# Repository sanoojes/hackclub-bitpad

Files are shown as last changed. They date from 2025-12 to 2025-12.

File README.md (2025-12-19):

# BitPad

A simple, customizable macropad with hot swapable keys, fully programmable keys, per-key RGB
lighting, multiple profiles for gaming, programming, editing, and more. uses QMK Firmware

## CAD

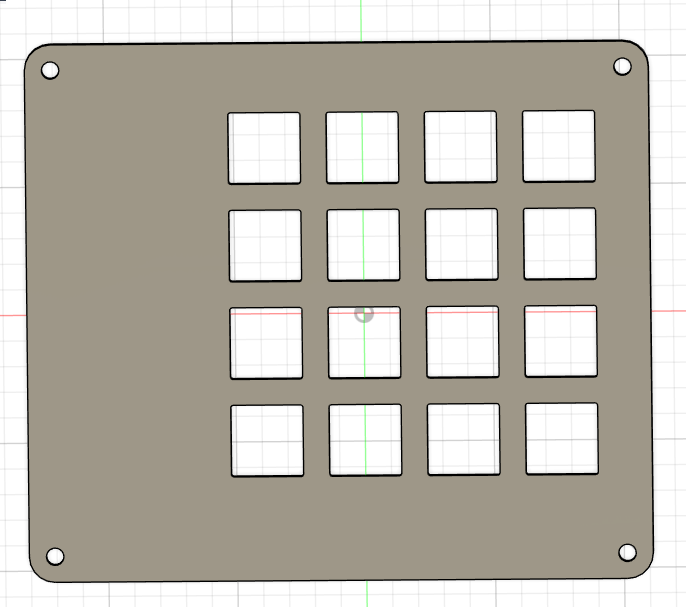
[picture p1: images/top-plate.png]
top_plate

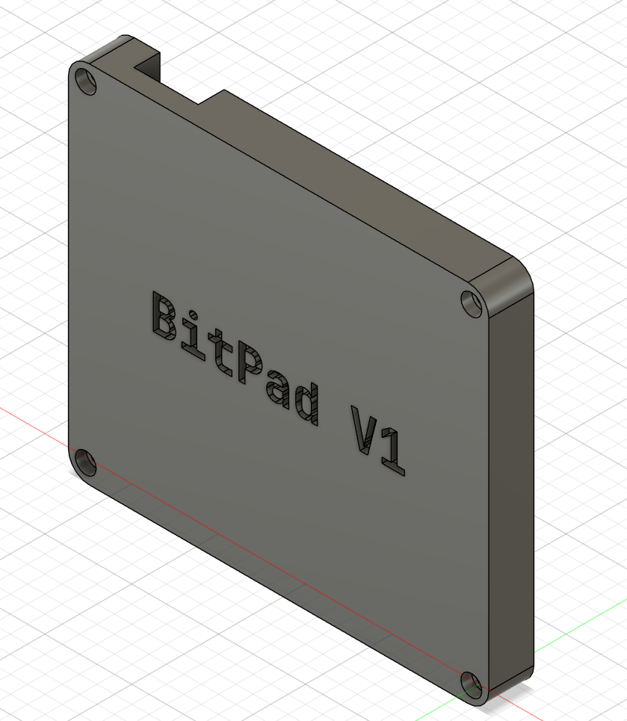
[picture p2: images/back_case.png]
back_case

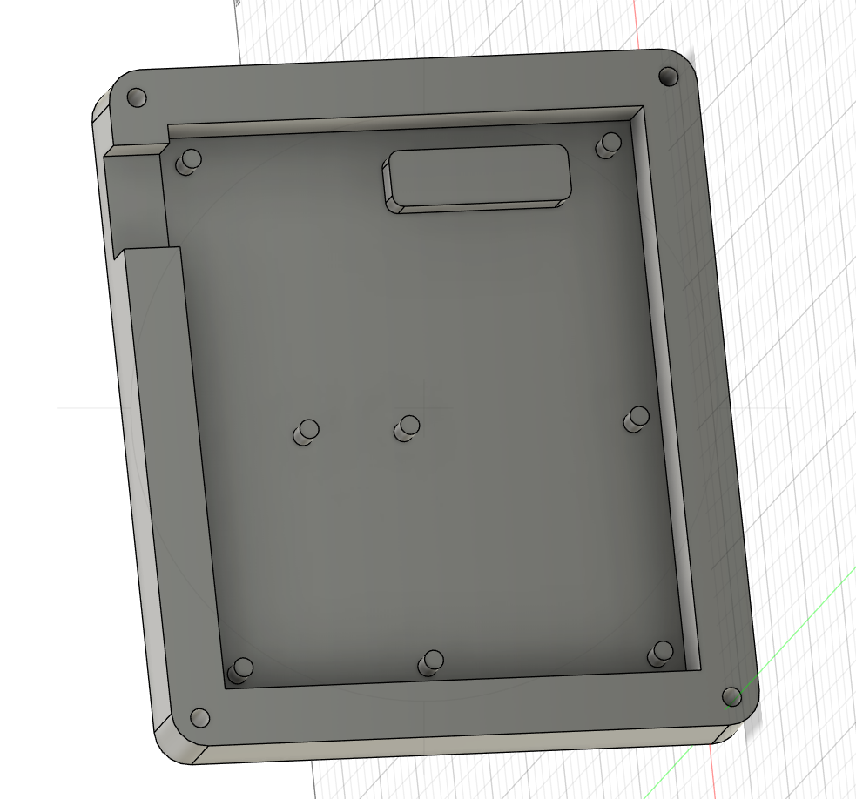
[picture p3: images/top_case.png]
top_case


## PCB

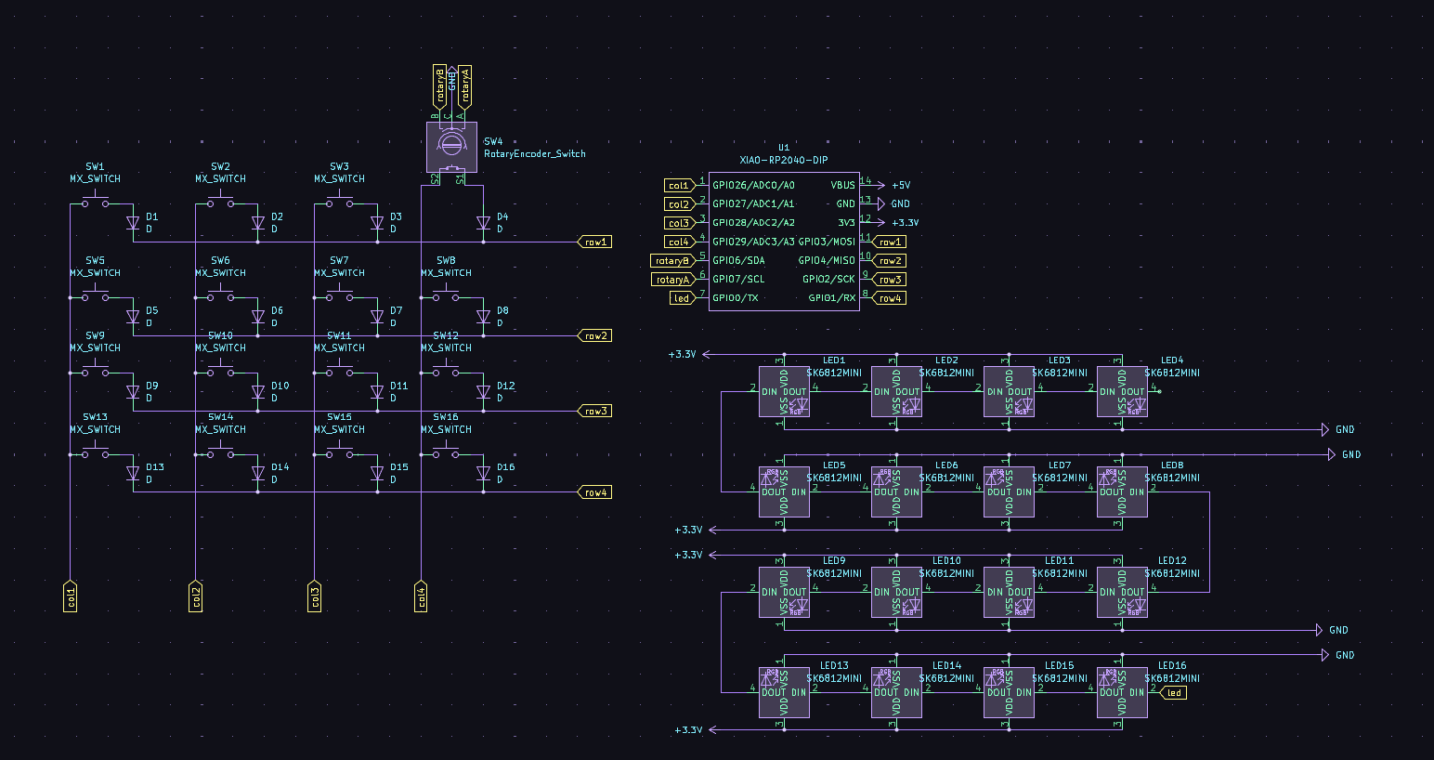
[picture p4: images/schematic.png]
schematics
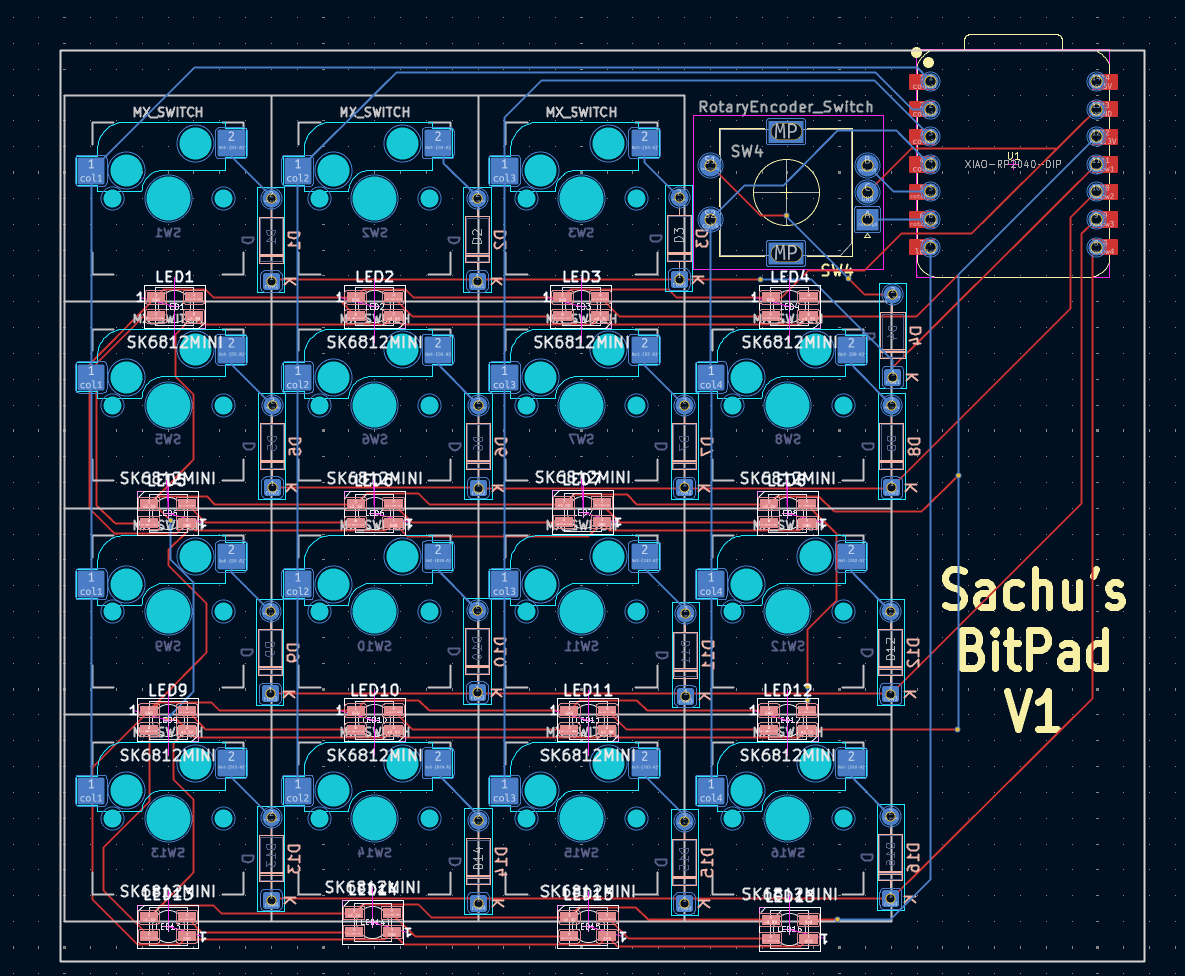
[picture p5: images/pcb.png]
pcb
 

## Firmware

Firmware available at [firmware/](firmware/) firmware will be tweaked and updated after i get the materials.

## BOM (Bill of materials)

Here's what I used for the device:

- 1x XIAO_RP2040 module
- 1x SK6812 Mini LEDs
- 1x EC11 Rotary Encoder
- 4x M3x16mm screws
- 4x M3x5mmx4mm inserts
- 16x Cherry MX Hotswappable Switches
- 16x DSA Keycaps
- 3D Printed Case

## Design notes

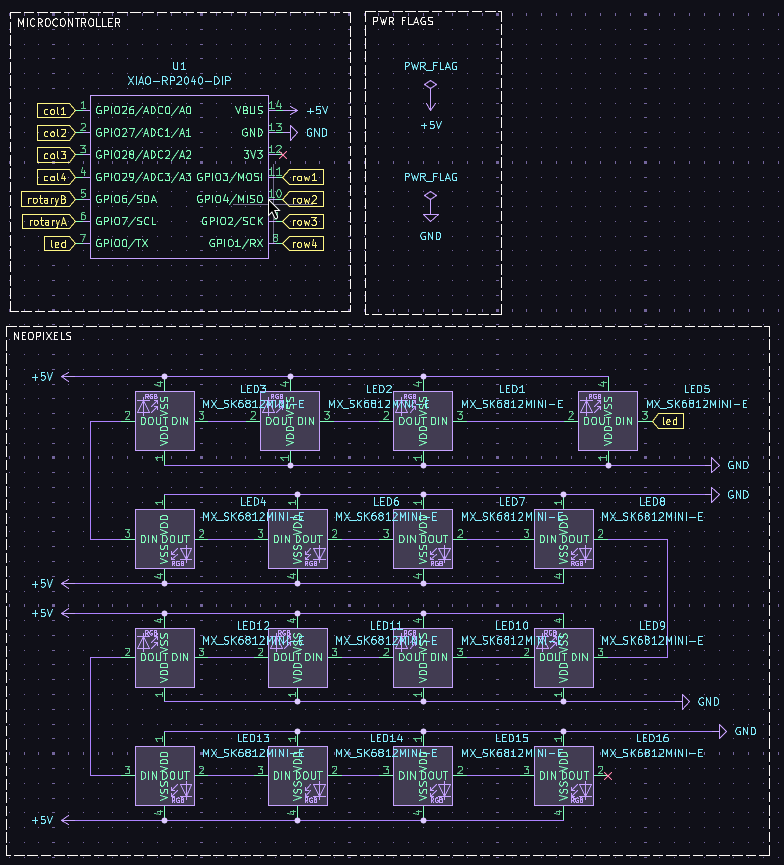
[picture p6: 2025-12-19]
images/schematic2.png

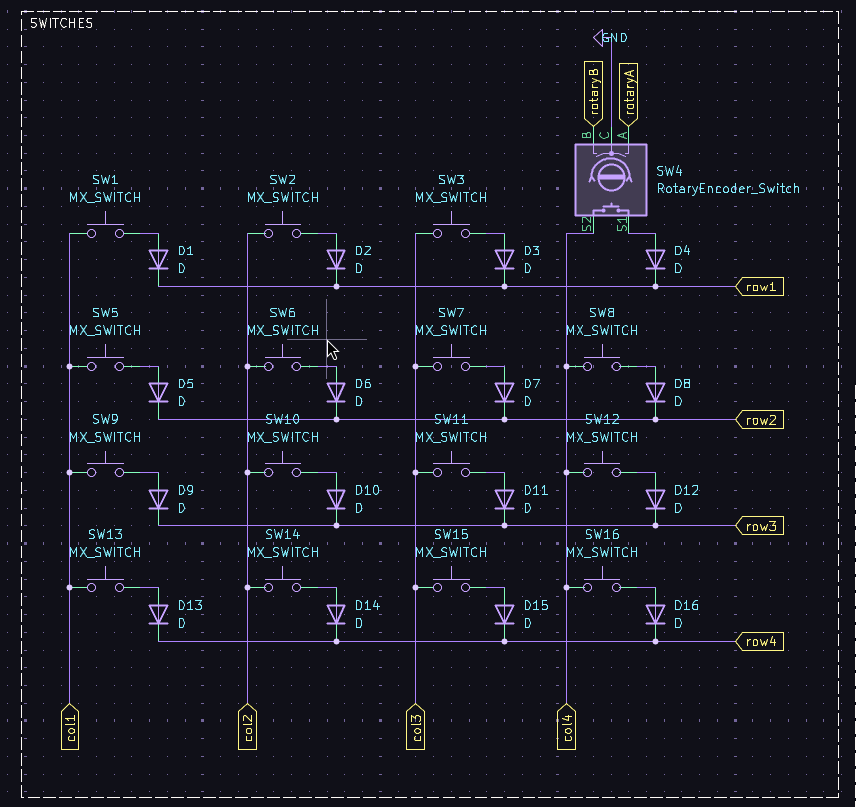
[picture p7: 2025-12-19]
images/schematic1.png

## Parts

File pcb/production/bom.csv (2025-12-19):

Designator | Footprint | Quantity | Value | LCSC Part #
D1, D10, D11, D12, D13, D14, D15, D16, D2, D3, D4, D5, D6, D7, D8, D9 | D_DO-35_SOD27_P7.62mm_Horizontal | 16 | D
LED1, LED10, LED11, LED12, LED13, LED14, LED15, LED16, LED2, LED3, LED4, LED5, LED6, LED7, LED8, LED9 | LED_MX_6028R | 16 | MX_SK6812MINI-E
SW1, SW10, SW11, SW12, SW13, SW14, SW15, SW16, SW2, SW3, SW5, SW6, SW7, SW8, SW9 | SW_MX_HS_CPG151101S11_1u | 15 | MX_SWITCH
SW4 | RotaryEncoder_Alps_EC11E-Switch_Vertical_H20mm | 1 | RotaryEncoder_Switch
U1 | XIAO-RP2040-DIP | 1 | XIAO-RP2040-DIP

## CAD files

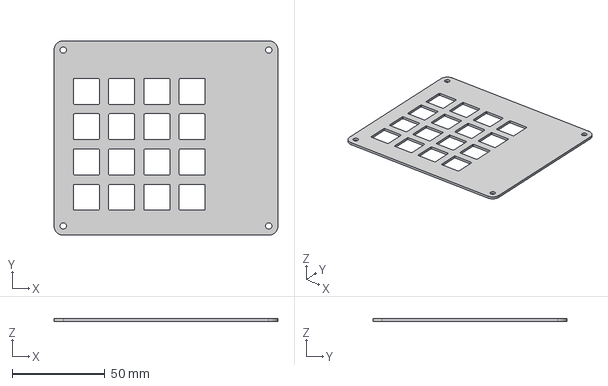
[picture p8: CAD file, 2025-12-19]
cad/top-plate.step
121.0 x 105.0 x 1.50 mm

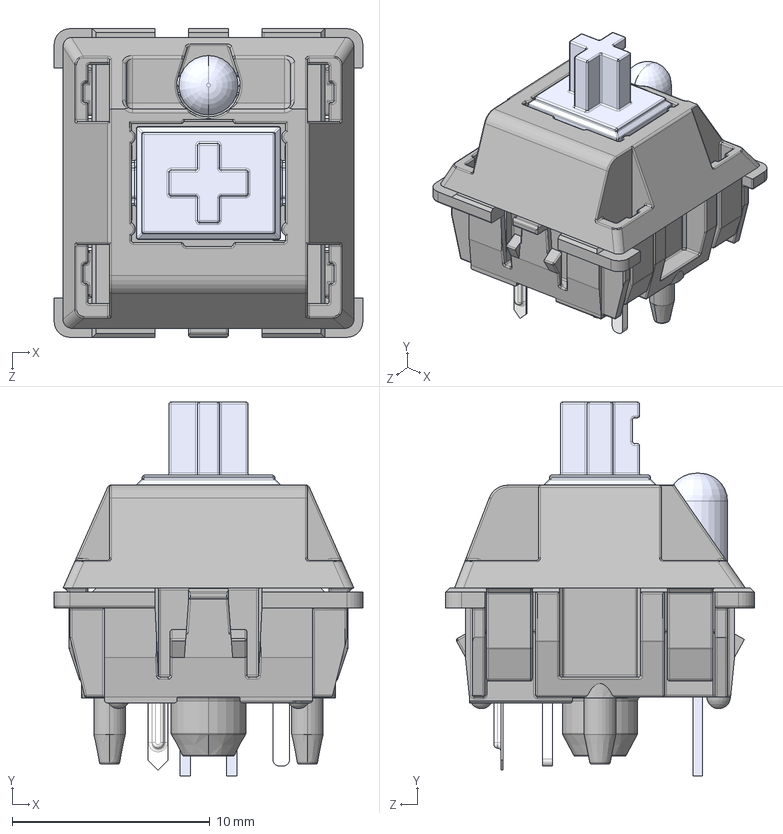
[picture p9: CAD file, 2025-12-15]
pcb/3dmodels/MX .STEP
15.6 x 18.9 x 15.6 mm
MX 轴 按键′_ü___¨1
MX 轴 轴体áì_¨￠¨__
MX粣 拸簽LEDLEDLED
MX轴 轴体 底部 μ×2__默认_á2____è_
针脚___默认__è_

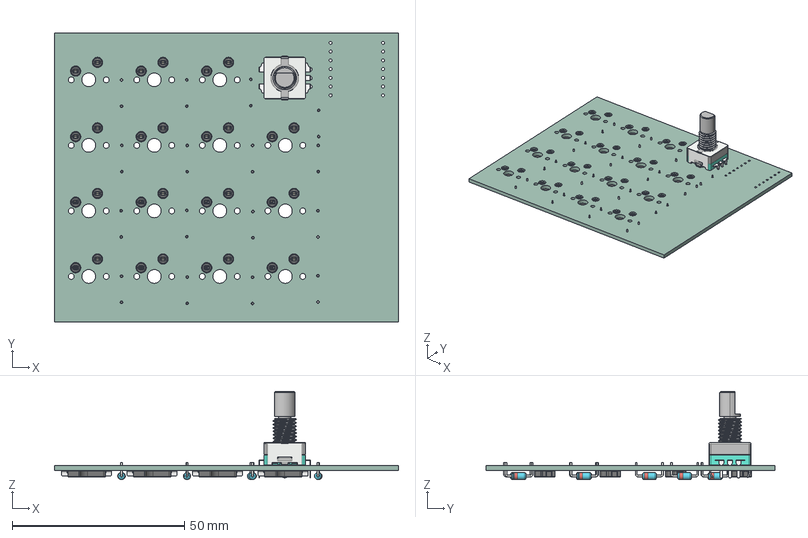
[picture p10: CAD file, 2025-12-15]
pcb/pcb.step
100.0 x 84.0 x 25.6 mm
rotary-encoder
D_DO-35_SOD27_P7.62mm_Horizontal x 16
MX-Hotswap-Socket x 15
pcb_PCB

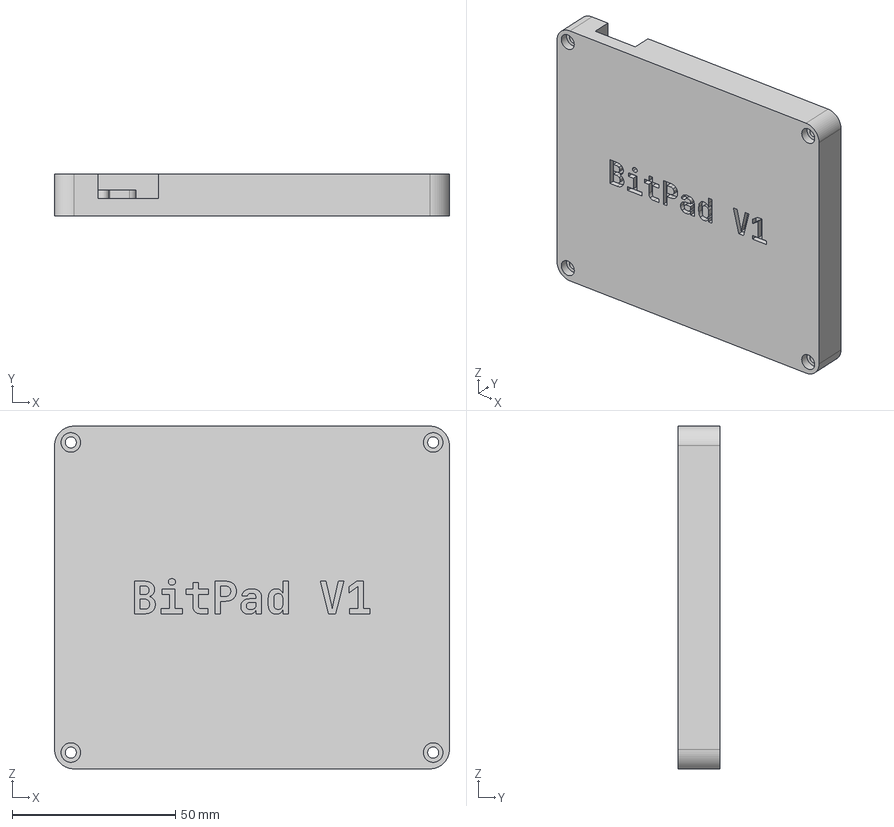
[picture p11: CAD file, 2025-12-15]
cad/case.step
121.0 x 13.0 x 105.0 mm

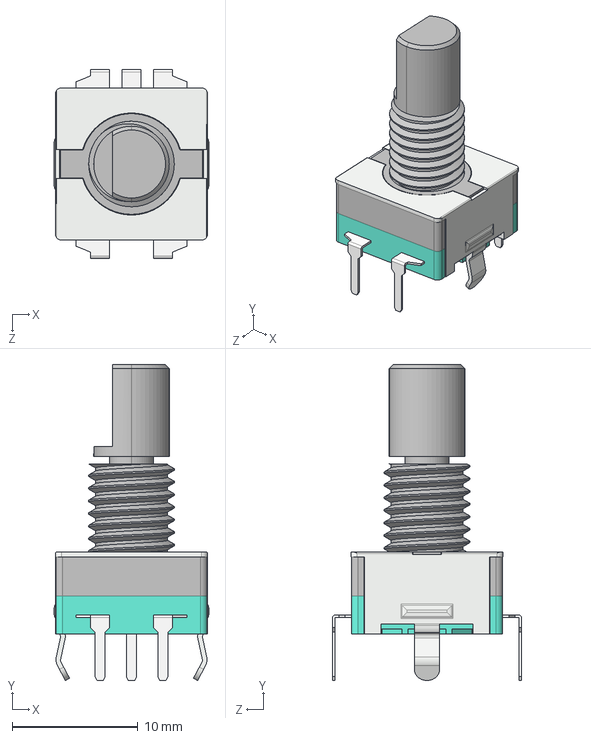
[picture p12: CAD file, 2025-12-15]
pcb/3dmodels/rotary-encoder.STEP
12.3 x 25.1 x 15.0 mm

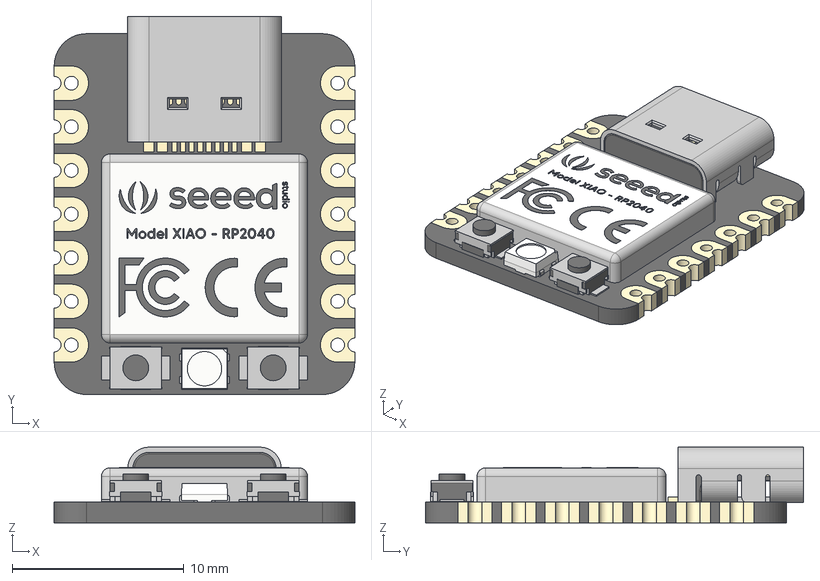
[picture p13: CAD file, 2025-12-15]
pcb/3dmodels/Seeed Studio XIAO RP2040 v26.step
17.5 x 22.0 x 4.40 mm
type-c v2
smd_button v3
DOUT
DIN
VSS
VDD
smd_button v3(Mirror)

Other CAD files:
cad/case.f3d
cad/case.stl
cad/top-plate.f3d

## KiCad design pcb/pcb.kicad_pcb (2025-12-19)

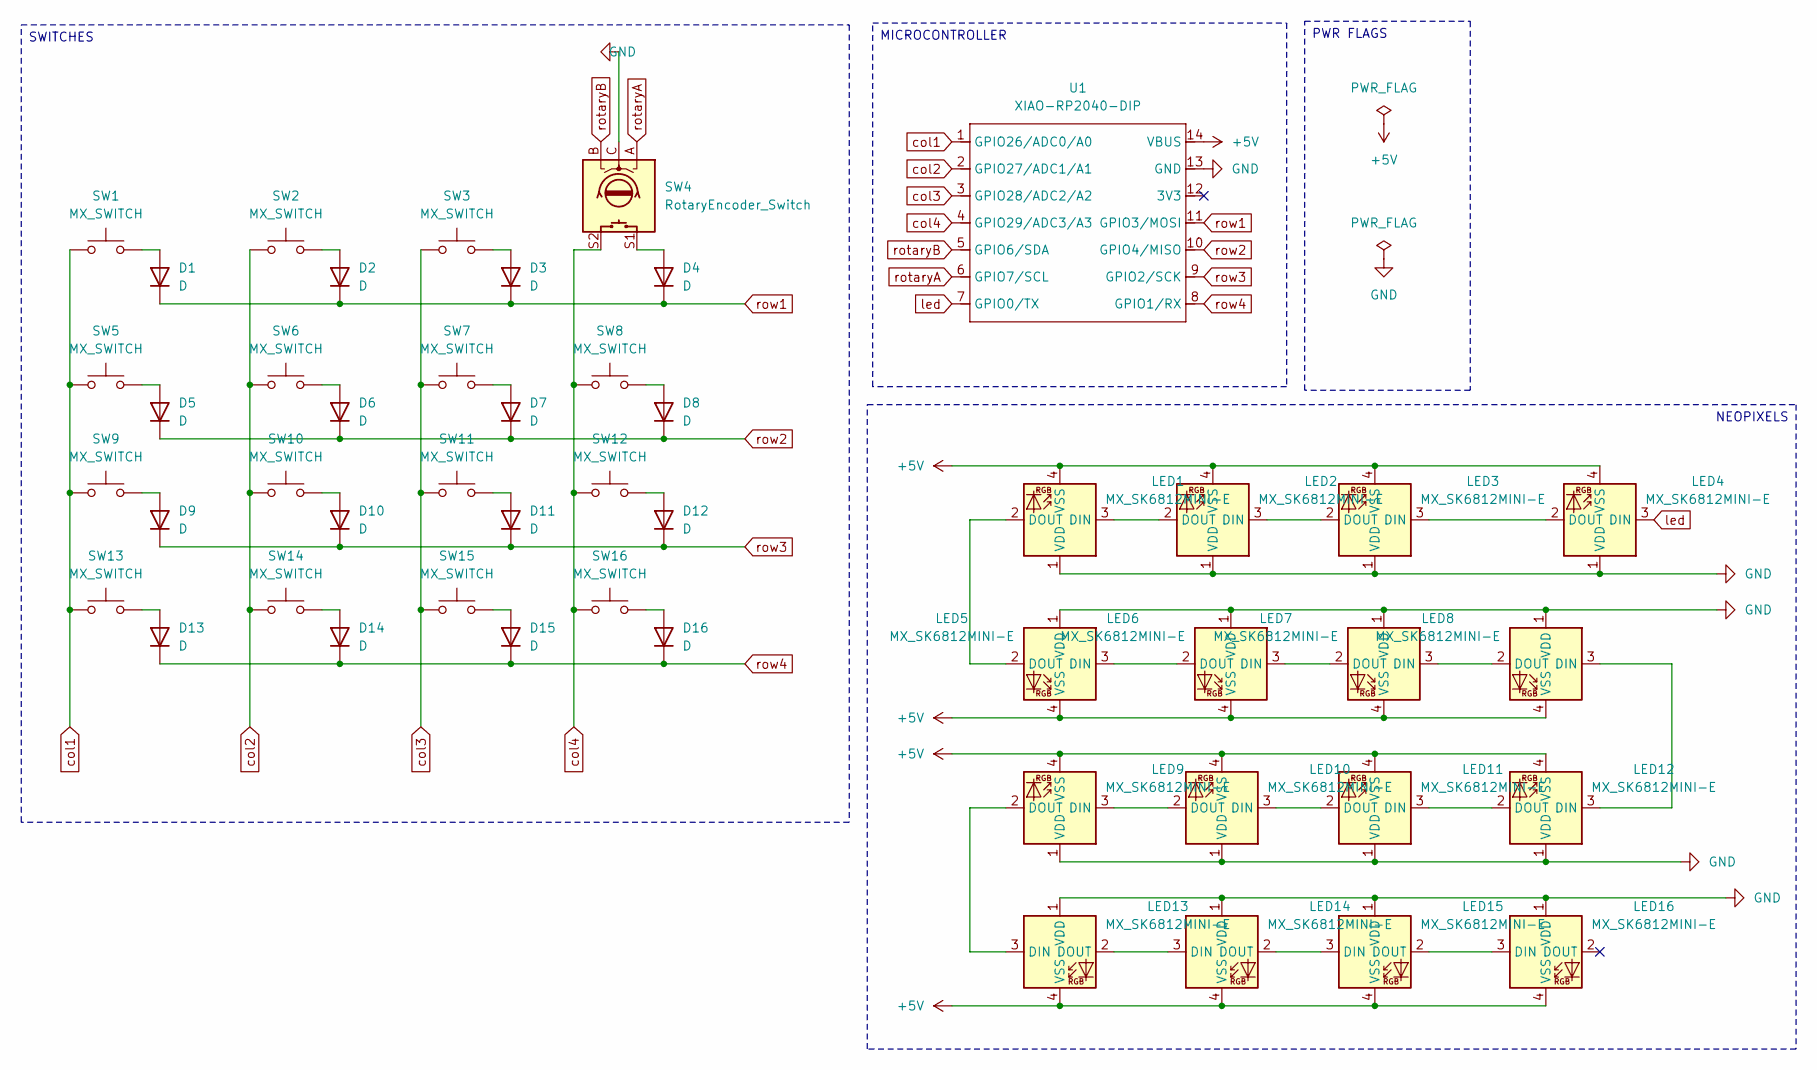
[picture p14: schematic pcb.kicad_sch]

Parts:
D1, D2, D3, D4, D5, D6, D7, D8, D9, D10, D11, D12, D13, D14, D15, D16: D; D_DO-35_SOD27_P7.62mm_Horizontal
LED1, LED2, LED3, LED4, LED5, LED6, LED7, LED8, LED9, LED10, LED11, LED12, LED13, LED14, LED15, LED16: MX_SK6812MINI-E; LED_MX_6028R
SW1, SW2, SW3, SW5, SW6, SW7, SW8, SW9, SW10, SW11, SW12, SW13, SW14, SW15, SW16: MX_SWITCH; SW_MX_HS_CPG151101S11_1u
SW4: RotaryEncoder_Switch; RotaryEncoder_Alps_EC11E-Switch_Vertical_H20mm
U1: XIAO-RP2040-DIP

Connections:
+5V: LED1.4 (VSS), LED2.4 (VSS), LED3.4 (VSS), LED4.4 (VSS), LED5.4 (VSS), LED6.4 (VSS), LED7.4 (VSS), LED8.4 (VSS), LED9.4 (VSS), LED10.4 (VSS), LED11.4 (VSS), LED12.4 (VSS), LED13.4 (VSS), LED14.4 (VSS), LED15.4 (VSS), LED16.4 (VSS), U1.14 (VBUS)
GND: LED1.1 (VDD), LED2.1 (VDD), LED3.1 (VDD), LED4.1 (VDD), LED5.1 (VDD), LED6.1 (VDD), LED7.1 (VDD), LED8.1 (VDD), LED9.1 (VDD), LED10.1 (VDD), LED11.1 (VDD), LED12.1 (VDD), LED13.1 (VDD), LED14.1 (VDD), LED15.1 (VDD), LED16.1 (VDD), SW4.C, U1.13 (GND)
unnamed: D1.2 (A), SW1.2
unnamed: D2.2 (A), SW2.2
unnamed: D3.2 (A), SW3.2
unnamed: D4.2 (A), SW4.S1
unnamed: D5.2 (A), SW5.2
unnamed: D6.2 (A), SW6.2
unnamed: D7.2 (A), SW7.2
unnamed: D8.2 (A), SW8.2
unnamed: D9.2 (A), SW9.2
unnamed: D10.2 (A), SW10.2
unnamed: D11.2 (A), SW11.2
unnamed: D12.2 (A), SW12.2
unnamed: D13.2 (A), SW13.2
unnamed: D14.2 (A), SW14.2
unnamed: D15.2 (A), SW15.2
unnamed: D16.2 (A), SW16.2
unnamed: LED1.3 (DIN), LED2.2 (DOUT)
unnamed: LED1.2 (DOUT), LED5.2 (DOUT)
unnamed: LED2.3 (DIN), LED3.2 (DOUT)
unnamed: LED3.3 (DIN), LED4.2 (DOUT)
unnamed: LED5.3 (DIN), LED6.2 (DOUT)
unnamed: LED6.3 (DIN), LED7.2 (DOUT)
unnamed: LED7.3 (DIN), LED8.2 (DOUT)
unnamed: LED10.3 (DIN), LED11.2 (DOUT)
unnamed: LED9.3 (DIN), LED10.2 (DOUT)
unnamed: LED11.3 (DIN), LED12.2 (DOUT)
unnamed: LED8.3 (DIN), LED12.3 (DIN)
unnamed: LED9.2 (DOUT), LED13.3 (DIN)
unnamed: LED13.2 (DOUT), LED14.3 (DIN)
unnamed: LED14.2 (DOUT), LED15.3 (DIN)
unnamed: LED15.2 (DOUT), LED16.3 (DIN)
col1: SW1.1, SW5.1, SW9.1, SW13.1, U1.1 (GPIO26/ADC0/A0)
col2: SW2.1, SW6.1, SW10.1, SW14.1, U1.2 (GPIO27/ADC1/A1)
col3: SW3.1, SW7.1, SW11.1, SW15.1, U1.3 (GPIO28/ADC2/A2)
col4: SW4.S2, SW8.1, SW12.1, SW16.1, U1.4 (GPIO29/ADC3/A3)
led: LED4.3 (DIN), U1.7 (GPIO0/TX)
rotaryA: SW4.A, U1.6 (GPIO7/SCL)
rotaryB: SW4.B, U1.5 (GPIO6/SDA)
row1: D1.1 (K), D2.1 (K), D3.1 (K), D4.1 (K), U1.11 (GPIO3/MOSI)
row2: D5.1 (K), D6.1 (K), D7.1 (K), D8.1 (K), U1.10 (GPIO4/MISO)
row3: D9.1 (K), D10.1 (K), D11.1 (K), D12.1 (K), U1.9 (GPIO2/SCK)
row4: D13.1 (K), D14.1 (K), D15.1 (K), D16.1 (K), U1.8 (GPIO1/RX)

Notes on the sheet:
PWR FLAGS
SWITCHES
NEOPIXELS
MICROCONTROLLER

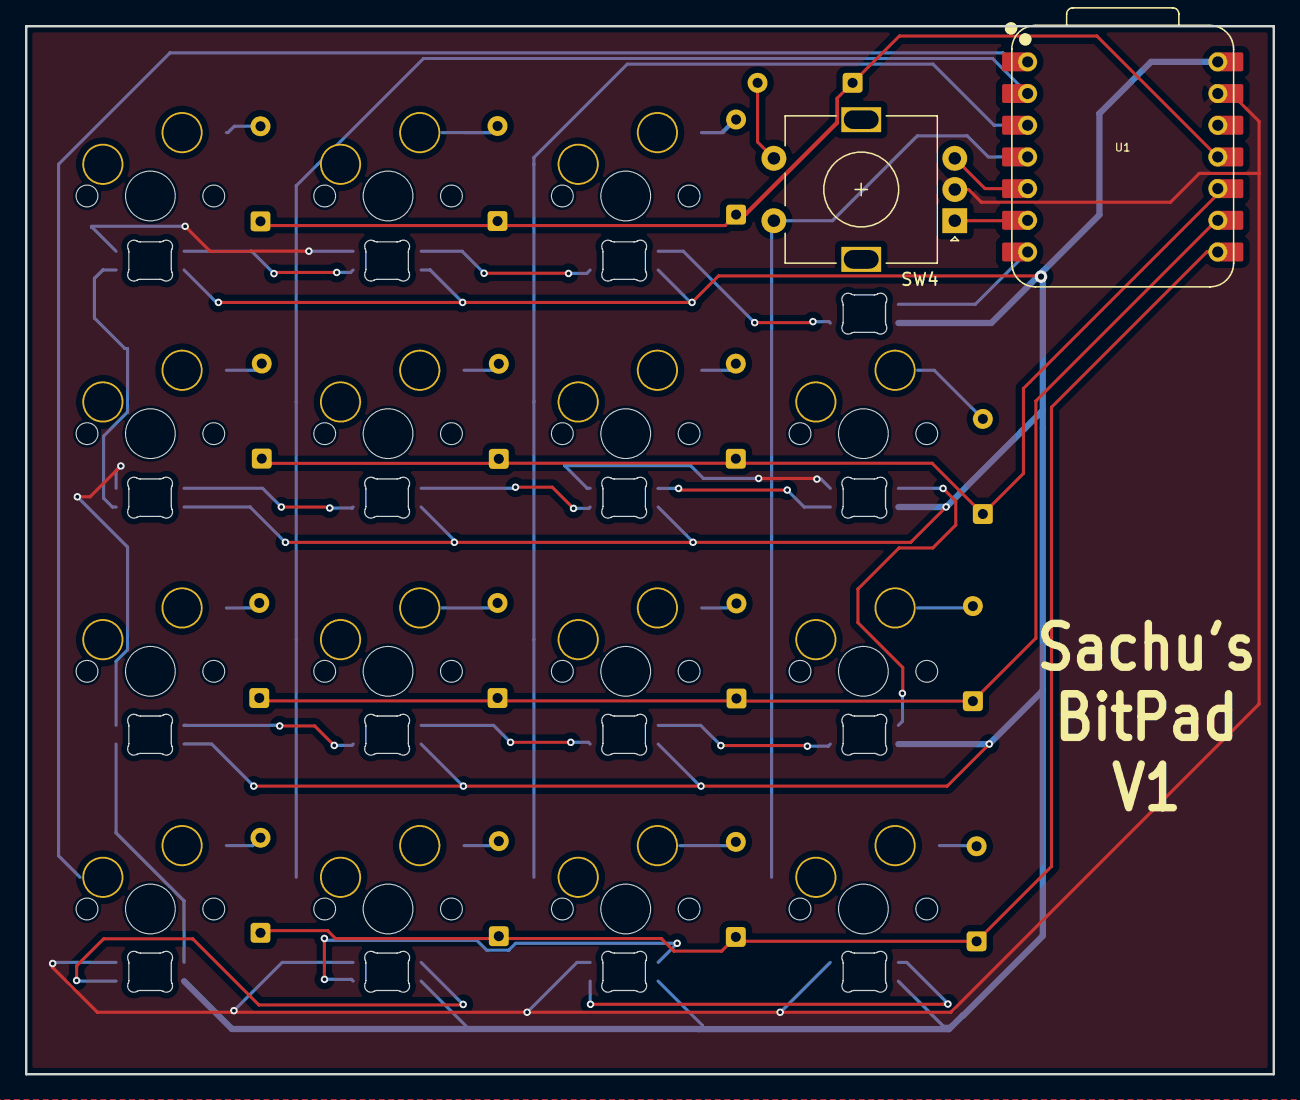
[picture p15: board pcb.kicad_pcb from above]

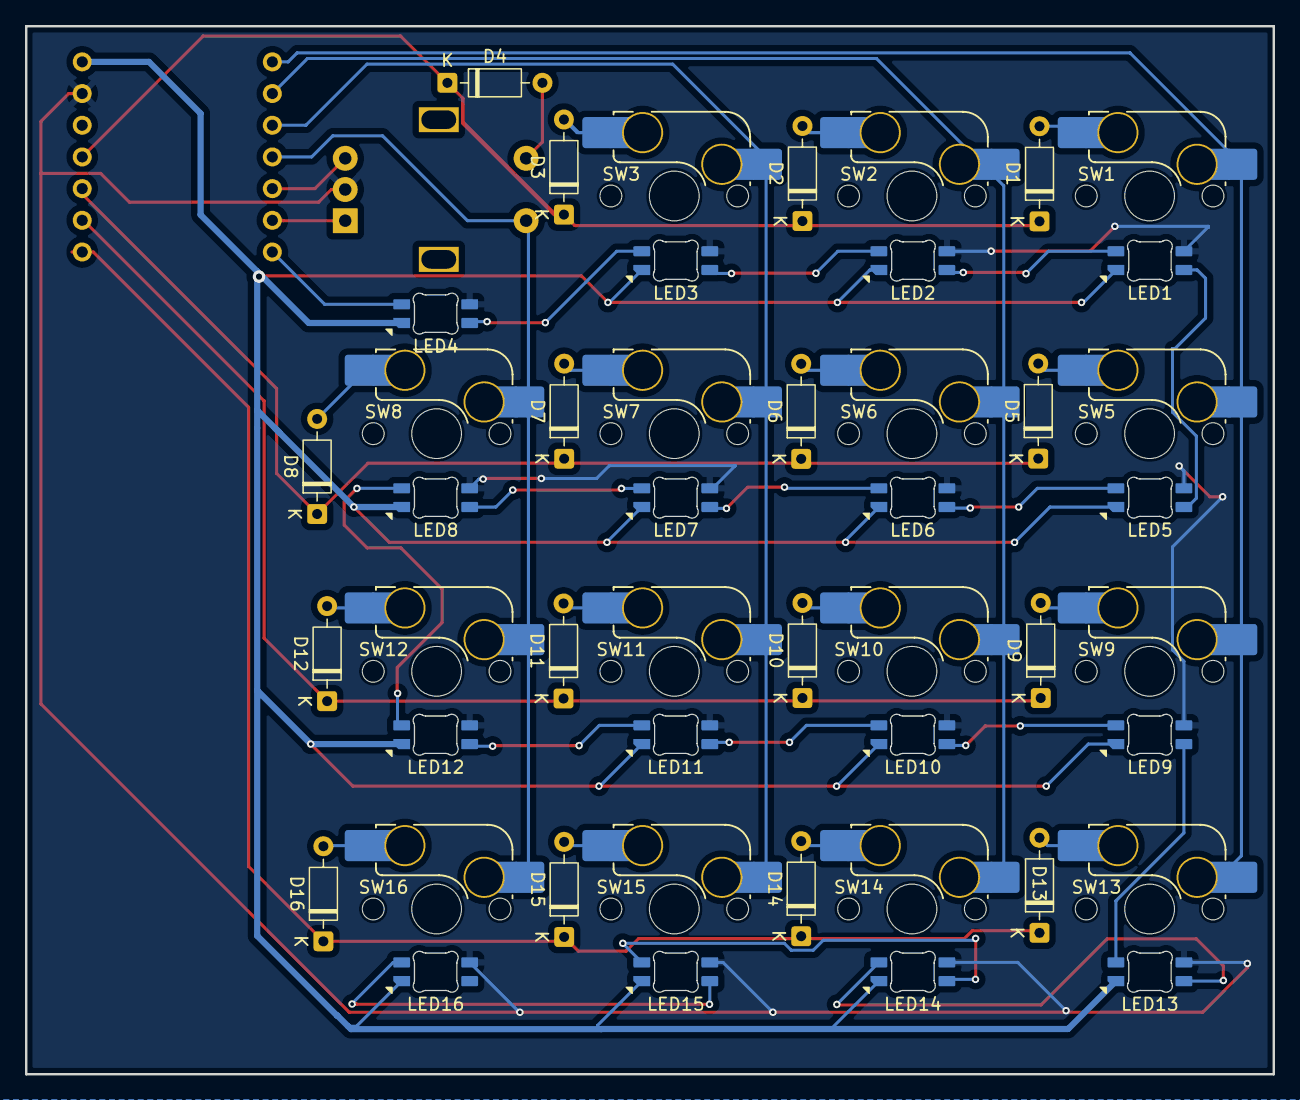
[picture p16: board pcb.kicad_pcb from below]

Board: 2 copper layers, 100.0 x 84.0 mm, 49 parts (47 on the bottom side), 44 nets.

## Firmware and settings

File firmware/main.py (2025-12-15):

# NOTE: I will try to migrate to qmk soon.

print("Starting")

import board

from kmk.kmk_keyboard import KMKKeyboard
from kmk.keys import KC
from kmk.scanners import DiodeOrientation
from kmk.modules.encoder import EncoderHandler
from kmk.extensions.media_keys import MediaKeys

keyboard = KMKKeyboard()

keyboard.col_pins = (board.GP26, board.GP27, board.GP28, board.GP29)
keyboard.row_pins = (board.GP3, board.GP4, board.GP2, board.GP1)
keyboard.diode_orientation = DiodeOrientation.COL2ROW

encoder = EncoderHandler()
encoder.pins = (
    (board.GP7, board.GP6, None),  
)
encoder.map = [
    ((KC.VOLD, KC.VOLU, KC.NO),),  
]
keyboard.modules.append(encoder)
keyboard.extensions.append(MediaKeys())

keyboard.keymap = [
    [
        KC.N1, KC.N2, KC.N3, KC.MUTE,   
        KC.N4, KC.N5, KC.N6, KC.N7,     
        KC.N8, KC.N9, KC.N0, KC.ENT,    
        KC.A,  KC.B,  KC.C,  KC.D,      
    ],
]

if __name__ == "__main__":
    keyboard.go()

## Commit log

2025-12-15 init: initial commit
    [_old_pcb.kicad_pcb, bom.csv, designators.csv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]
2025-12-15 add 3d model for the xiao
    [Seeed Studio XIAO RP2040 v26.f3d, Seeed Studio XIAO RP2040 v26.step, pcb.kicad_pcb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]
2025-12-15 add case and pcb libraries
    [MX .STEP, Seeed Studio XIAO RP2040 v26.f3d, Seeed Studio XIAO RP2040 v26.step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]
2025-12-15 feat: add step file for the case
    [case.step]
2025-12-16 feat: add top plate
    [top-plate.f3d, top-plate.step]
2025-12-19 update schematics and footprints to match sk6812mini-e
    [bom.csv, pcb.kicad_pcb, pcb.kicad_sch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]
